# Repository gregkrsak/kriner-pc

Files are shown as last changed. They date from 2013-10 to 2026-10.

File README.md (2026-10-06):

# Kriner Power Converter



A small open-source DC power switch with pushbutton controls and a separate logic-level enable input.

The Kriner Power Converter is designed to switch relatively high-current DC loads either from a microcontroller or from controls directly on the board. No firmware is required.

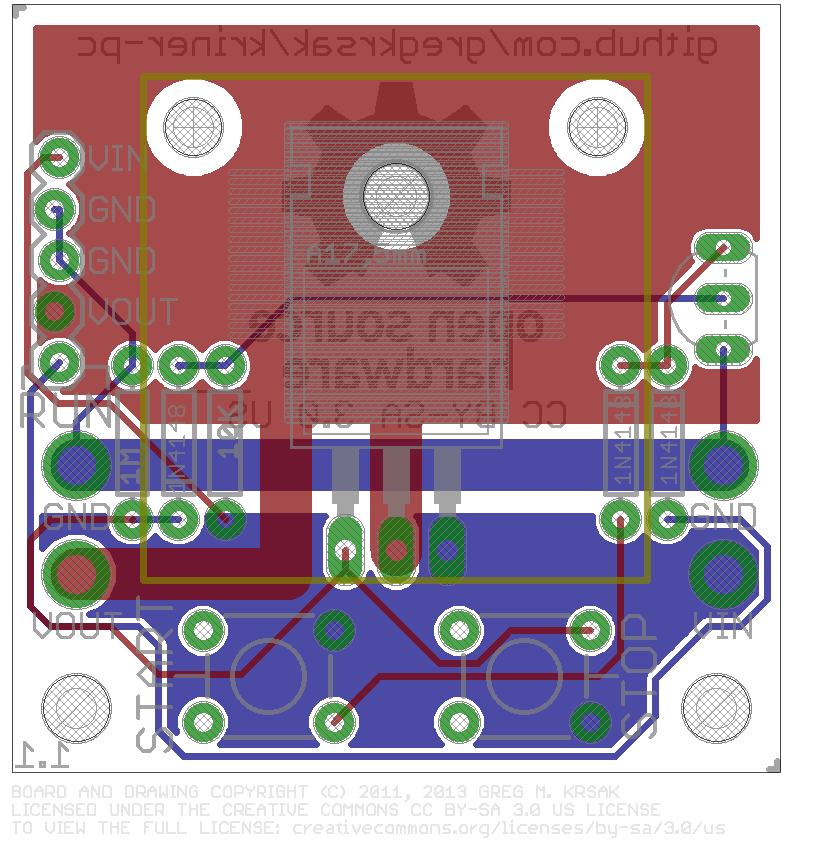
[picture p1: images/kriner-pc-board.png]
Kriner Power Converter board


## What it does

The board uses a P-channel MOSFET as a high-side switch between `VIN` and `VOUT`.

There are three ways to control the output:

- **START** — manually enables `VOUT` while pressed.
- **STOP** — manually disables `VOUT` while pressed.
- **RUN** — logic-high input that enables `VOUT`.

`STOP` takes priority over either START or RUN.

In other words:

| START | STOP | RUN | VOUT |
| --- | --- | --- | --- |
| Released | Released | Low | Off |
| Pressed | Released | Low | On |
| Released | Released | High | On |
| Pressed | Released | High | On |
| Any | Pressed | Any | Off |

The pushbuttons are momentary controls rather than latching ON/OFF switches.

## Specifications

| | |
| --- | --- |
| Input voltage | 5–12 VDC |
| Switching | P-channel MOSFET, high side |
| Manual controls | START / STOP |
| External control | Logic-high RUN input |
| PCB size | Approximately 38.1 × 38.1 mm (1.5 × 1.5 in) |
| Construction | Through-hole |
| PCB layers | 2 |
| CAD format | EAGLE 6.5.0 |
| Design revision | 1.1 |
| Firmware | None |

The design has been tested from **5–12 VDC** and has been used with loads up to **15 A with forced-air cooling**.

See [Current and thermal notes](#current-and-thermal-notes) before treating 15 A as a continuous design rating.

## Connections

### Main header — JP1

| Pin | Signal | Purpose |
| --- | --- | --- |
| 1 | `VIN` | Positive supply input |
| 2 | `GND` | Ground |
| 3 | `GND` | Ground |
| 4 | `VOUT` | Switched positive output |
| 5 | `RUN` | Logic-high enable |

The board silkscreen identifies the same connections as:

`VIN` · `GND` · `GND` · `VOUT` · `RUN`

The RUN signal is named `5V` internally in the EAGLE schematic. It is intended as a logic-level control input for devices such as microcontrollers. A formal input-high threshold is not specified, so verify compatibility when using logic levels other than 5 V.

### 2 mm power connections

The board also provides separate 2 mm through-hole connections for:

- `VIN`
- `VOUT`
- `GND`
- `GND`

These provide an alternative to carrying load current through the main header.

## Circuit

The switching stage is built around an **FQP27P06 P-channel MOSFET** (`Q2`).

An **FJN3305RTA NPN transistor** (`Q1`) and three **1N4148** diodes combine the START and RUN inputs and control the MOSFET gate. The STOP switch acts directly on the gate-control network so that it overrides an asserted enable signal.

The basic logic is:

```text
                 +------ START button
                 |
Enable ----------+------ RUN logic input
                 |
                 v
          NPN control stage
                 |
                 v
VIN ------ P-channel MOSFET ------ VOUT
                 ^
                 |
                 +------ STOP button
```

This is a switch, not a voltage regulator: when enabled, `VOUT` is the switched version of `VIN`.

## Main components

| Ref. | Part | Description |
| --- | --- | --- |
| Q1 | FJN3305RTA | NPN transistor |
| Q2 | FQP27P06 | P-channel power MOSFET, TO-220 |
| D1–D3 | 1N4148 | Small-signal diodes |
| R1 | 10 kΩ | Resistor |
| R2 | 1 MΩ | Resistor |
| S1 | 6 mm tactile switch | START |
| S2 | 6 mm tactile switch | STOP |
| JP1 | 1×5 PTH header | Main connection header |

The PCB also includes two mounting/standoff holes and four dedicated 2 mm power connection holes.

## Schematic

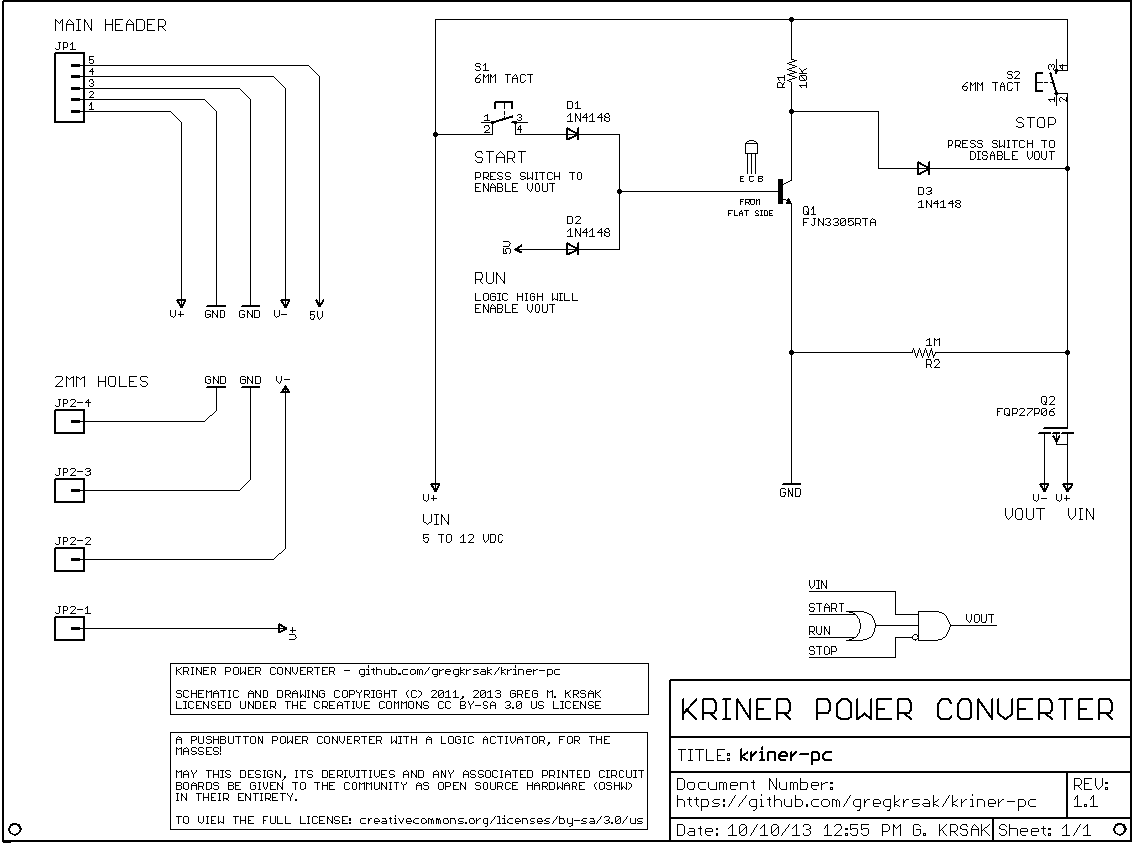
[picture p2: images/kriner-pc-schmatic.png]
Kriner Power Converter schematic


The EAGLE schematic and board layout are included in the repository and can be modified directly.

## Repository layout

```text
kriner-pc/
├── eagle/
│   ├── kriner-pc.brd
│   └── kriner-pc.sch
├── images/
│   ├── kriner-pc-board.png
│   ├── kriner-pc-schmatic.png
│   └── oshw-logo-600-px-mirror.bmp
├── .gitignore
├── LICENSE
└── README.md
```

## Current and thermal notes

The Kriner Power Converter is an open-source hardware design rather than a fully characterized commercial power module.

The circuit has been tested from 5–12 VDC has the potential to be used with loads up to 15 A with forced-air cooling. That figure should not be interpreted as a guaranteed continuous-current rating under arbitrary conditions.

Actual current capability depends on factors including:

- MOSFET dissipation and heatsinking
- PCB copper temperature
- airflow
- wiring and connector resistance
- ambient temperature
- load characteristics
- startup and inrush current

Additional characterization would be useful for:

- inrush current
- MOSFET power dissipation
- turn-on time
- turn-off time

For a new application, verify electrical and thermal behavior under the actual intended load.

## Project status

The EAGLE design files identify the current board as **Revision 1.1**.

Potential future work tracked in the repository includes:

- inrush-current characterization
- power-dissipation documentation
- turn-on and turn-off timing
- validation of a physical Rev. 1.2 board
- migration of the schematic to KiCad

The EAGLE `.sch` and `.brd` files are the canonical design files for the project.

## Open-source hardware

The Kriner Power Converter is open-source hardware. The schematic, PCB layout, and derived boards may be studied, modified, and shared under the terms of the project license.

The design and drawings are licensed under the **Creative Commons Attribution-ShareAlike 3.0 United States License (CC BY-SA 3.0 US)**.

See [LICENSE](LICENSE) for the complete license text.

---

Designed by **Greg M. Krsak**.

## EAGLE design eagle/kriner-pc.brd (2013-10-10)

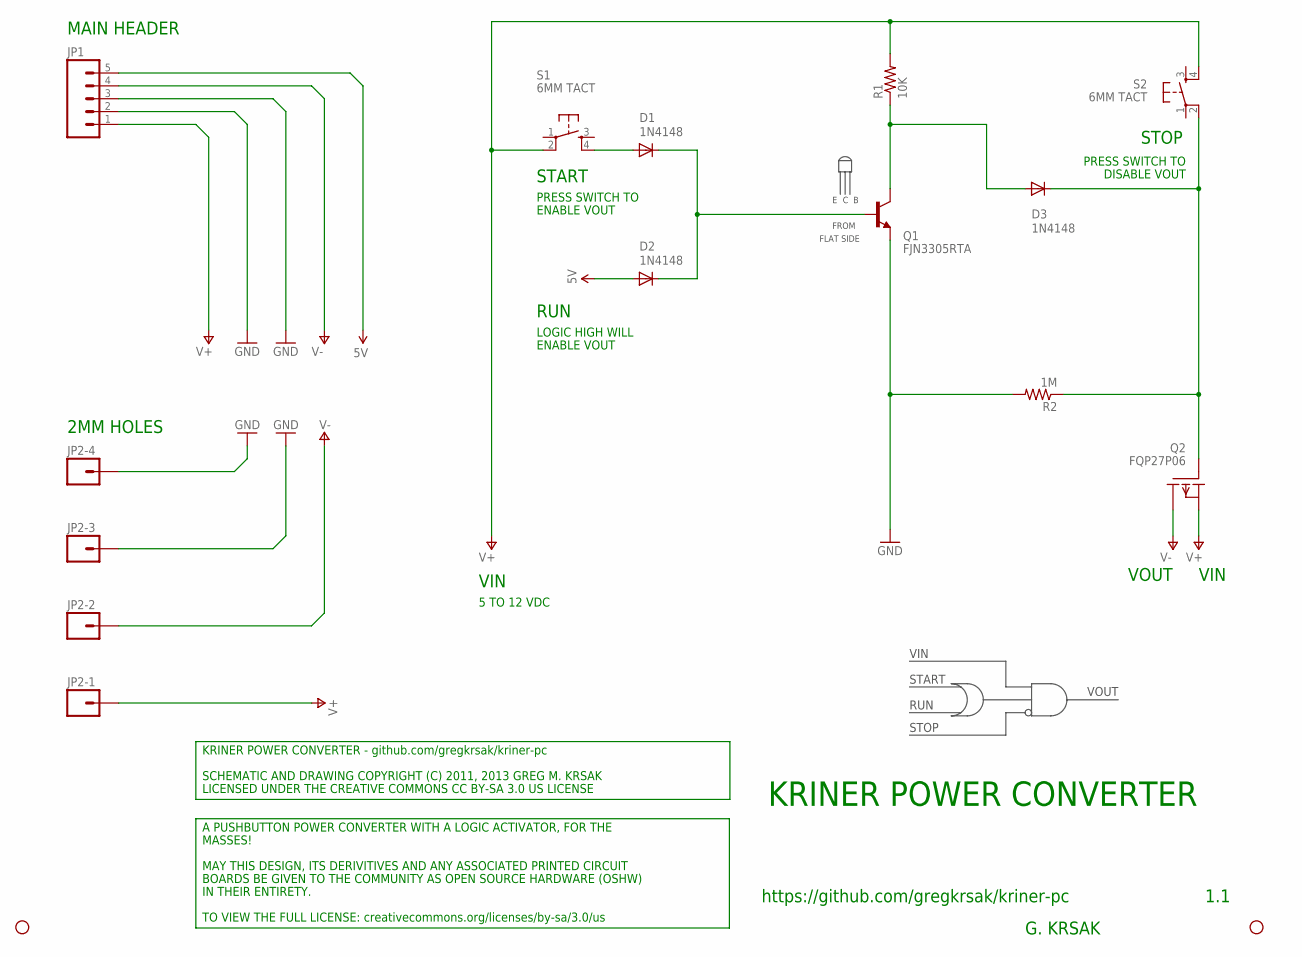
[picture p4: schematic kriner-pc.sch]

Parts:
D1, D2, D3: 1N4148; DIODE-1N4148
JP1: M05LOCK; 1X05_LOCK
JP2, JP3: STAND-OFF
JP2-1, JP2-2, JP2-3, JP2-4: M01PTH_2MM; 1X01_2MM
Q1: FJN3305RTA; TO92-ECB
Q2: FQP27P06; TO220
R1: 10K; AXIAL-0.3
R2: 1M; AXIAL-0.3
S1, S2: 6MM TACT; TACTILE-PTH

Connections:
5V: D2.A, JP1.5
GND: JP1.2, JP1.3, JP2-3.1, JP2-4.1, Q1.E, R2.P$2 (2)
unnamed: D1.C, D2.C, Q1.B
unnamed: D1.A, S1.4
unnamed: D3.C, Q2.1 (G), R2.P$1 (1), S2.2
unnamed: D3.A, Q1.C, R1.P$1 (1)
V+: JP1.1, JP2-1.1, Q2.3 (S), R1.P$2 (2), S1.2, S2.4
V-: JP1.4, JP2-2.1, Q2.2 (D)

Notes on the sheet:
1.1
https://github.com/gregkrsak/kriner-pc
KRINER POWER CONVERTER
START
STOP
RUN
VOUT
VIN
MAIN HEADER
2MM HOLES
A PUSHBUTTON POWER CONVERTER WITH A LOGIC ACTIVATOR, FOR THE
TO VIEW THE FULL LICENSE: creativecommons.org/licenses/by-sa/3.0/us
MAY THIS DESIGN, ITS DERIVITIVES AND ANY ASSOCIATED PRINTED CIRCUIT
BOARDS BE GIVEN TO THE COMMUNITY AS OPEN SOURCE HARDWARE (OSHW)
IN THEIR ENTIRETY.
KRINER POWER CONVERTER - github.com/gregkrsak/kriner-pc
LICENSED UNDER THE CREATIVE COMMONS CC BY-SA 3.0 US LICENSE
MASSES!
LOGIC HIGH WILL
ENABLE VOUT
PRESS SWITCH TO
DISABLE VOUT
5 TO 12 VDC
G. KRSAK
SCHEMATIC AND DRAWING COPYRIGHT (C) 2011, 2013 GREG M. KRSAK
FROM
FLAT SIDE

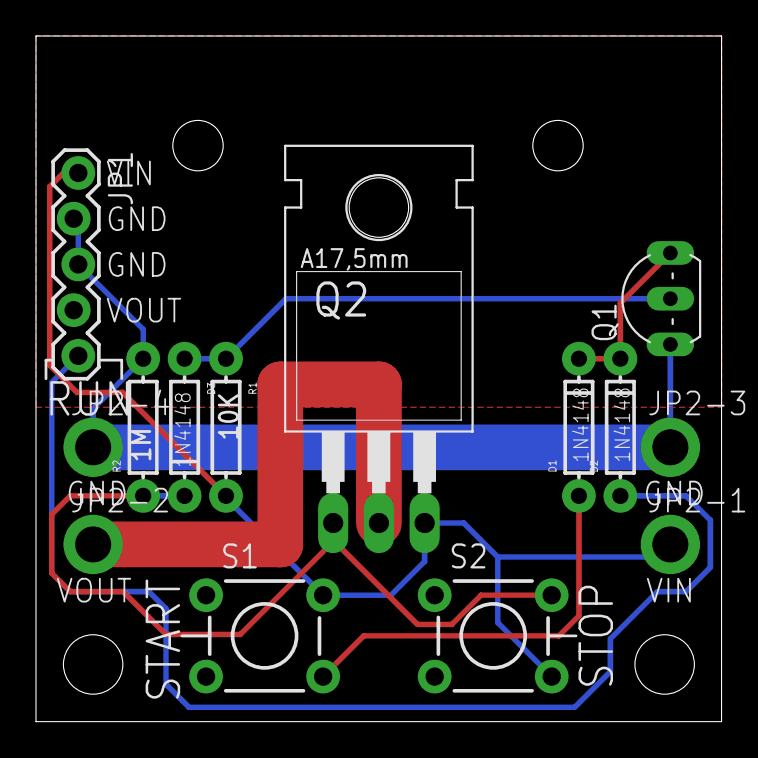
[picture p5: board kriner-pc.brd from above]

Board: 2 copper layers, 38.1 x 38.1 mm, 16 parts (0 on the bottom side), 8 nets.

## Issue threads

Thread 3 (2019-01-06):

Clarify power dissipation capabilities

gregkrsak, 2019-01-06:
Post pertinent information and a reference related to the P-channel power MOSFET's power dissipation capabilities.

gregkrsak, 2019-01-07:
Test on 1.2

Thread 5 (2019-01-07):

Schematic: Rename product to "Kriner Switch"

gregkrsak, 2019-01-07:
At least from an end-user's perspective, "power converter" may not be the best choice of words.

"Switch" is much more user friendly.

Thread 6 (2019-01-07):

Board: Rename product to "Kriner Switch"

gregkrsak, 2019-01-07:
At least from an end-user's perspective, "power converter" may not be the best choice of words.

"Switch" is much more user friendly.

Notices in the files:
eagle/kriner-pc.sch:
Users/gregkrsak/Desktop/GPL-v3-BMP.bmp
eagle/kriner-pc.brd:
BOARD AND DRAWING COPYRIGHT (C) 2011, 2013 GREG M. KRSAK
